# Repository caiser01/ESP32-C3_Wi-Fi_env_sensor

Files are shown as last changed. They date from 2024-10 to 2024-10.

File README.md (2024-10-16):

# ESP32-C3 Wi-Fi environment sensor node
<p>A Wi-Fi connected temperature, humidity, and pressure sensor node based around the Espressif ESP32-C3-MINI-1 and the Bosch BME280 Humidity/Pressure/Temperature sensor.</p>

<p align="center">
rev 1.0 PCB Revision 1.0 PCB
</p>

<p>The primary goal of this project is to provide a simple platform for monitoring the temperature and humidity of the spaces inside one's home. These wireless sensor nodes can be easily integrated with the free software packages such as Home Assistant (https://www.home-assistant.io) and ESPHome (https://esphome.io). Alternatively, the user can write their own fully custom firmware using ESP-IDF, Arduino, or MicroPython.</p>

<p>Through simple monitoring of the temperature and humidity in the different rooms of one's home it is possible to:
<br>
<ul>
  <li>Gain insight into the effectiveness of the home's heating and cooling (HVAC) system</li>
  <li>Determine if a space may need a humidifier/dehumidifier</li>
  <li>Identify spaces that may need additional insulation</li>
  <li>Find spaces with doors or windows that do not seal tightly</li>
</ul>
</p>
<p>Additionally, the barometric pressure sensing capability can provide realtime insight into changing local weather conditions.</p>

## Design
<p>This device was designed for measuring the basic ambient environmental conditions of an indoor space so that they may be remotely displayed instantly and/or logged for long-term monitoring. The ESP32-C3-MINI-1 was chosen for its small footprint and the numerous available coding frameworks including ESP-IDF, Arduino, MicroPython, and ESPHome. The device includes a built in charger for a lithium battery. The user has the option to power the sensor node from a USB-C cable or from a rechargeable lithium battery. Firmware flashing is also performed through the USB-C connector via the ESP32-C3's built in USB interface. Depending on the software and framework used, over-the-air (OTA) firmware flashing is also possible via Wi-Fi.</p>

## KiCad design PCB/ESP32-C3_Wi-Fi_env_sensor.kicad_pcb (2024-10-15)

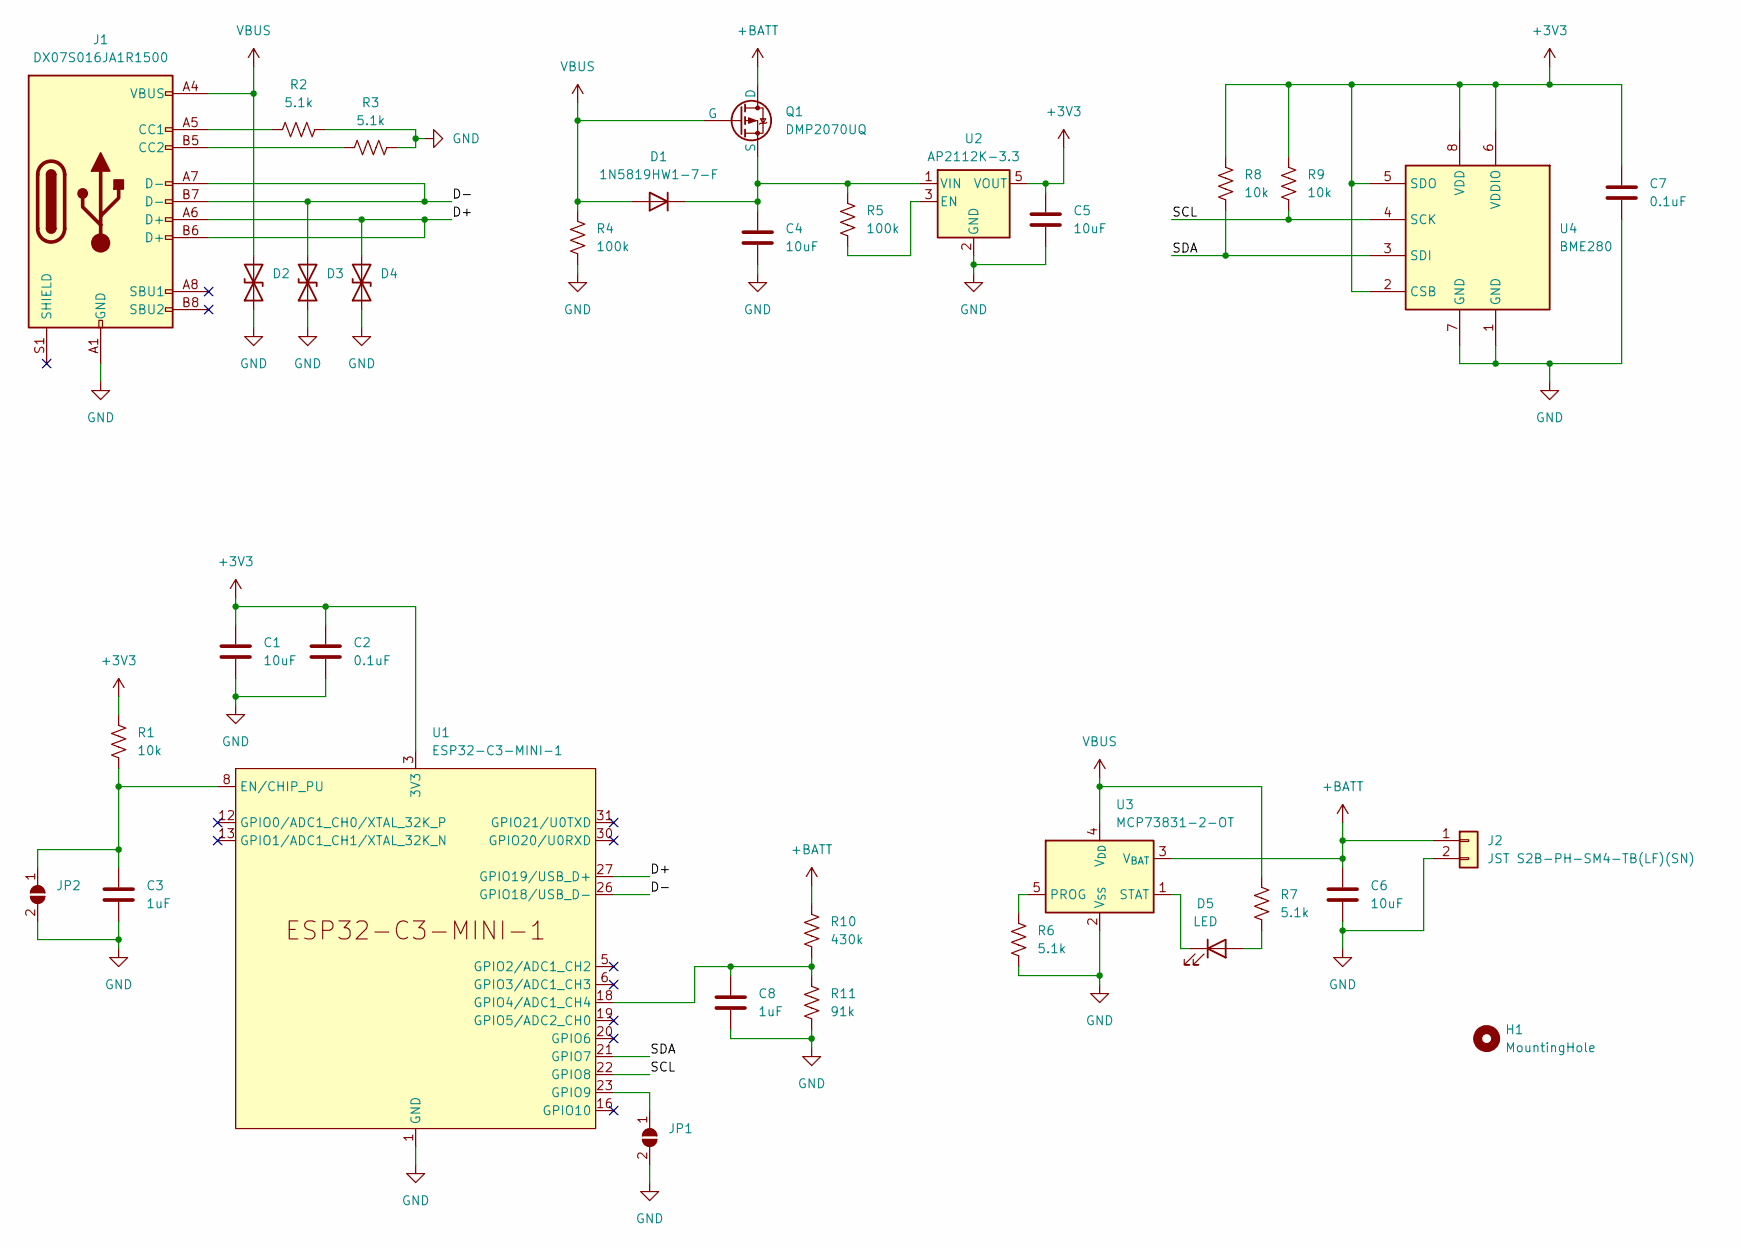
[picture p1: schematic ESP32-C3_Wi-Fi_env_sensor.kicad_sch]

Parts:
C1, C4, C5, C6: 10uF; C_0603_1608Metric_Pad1.08x0.95mm_HandSolder
C2, C7: 0.1uF; C_0603_1608Metric_Pad1.08x0.95mm_HandSolder
C3, C8: 1uF; C_0603_1608Metric_Pad1.08x0.95mm_HandSolder
D1: 1N5819HW1-7-F; D_SOD-123F
D2, D3, D4: LESD5D5.0CT1G; D_SOD-523
D5: LED; LED_0603_1608Metric_Pad1.05x0.95mm_HandSolder
H1: MountingHole; MountingHole_2.7mm_M2.5
J1: DX07S016JA1R1500; USB_C_Receptacle_JAE_DX07S016JA1R1500
J2: JST S2B-PH-SM4-TB(LF)(SN); JST_PH_S2B-PH-SM4-TB_1x02-1MP_P2.00mm_Horizontal
JP1, JP2: SolderJumper_2_Open; SolderJumper-2_P1.3mm_Open_Pad1.0x1.5mm
Q1: DMP2070UQ; SOT-23
R1, R8, R9: 10k; R_0402_1005Metric_Pad0.72x0.64mm_HandSolder
R2, R3, R6, R7: 5.1k; R_0603_1608Metric_Pad0.98x0.95mm_HandSolder
R4, R5: 100k; R_0603_1608Metric_Pad0.98x0.95mm_HandSolder
R10: 430k; R_0603_1608Metric_Pad0.98x0.95mm_HandSolder
R11: 91k; R_0603_1608Metric_Pad0.98x0.95mm_HandSolder
U1: ESP32-C3-MINI-1
U2: AP2112K-3.3; SOT-23-5
U3: MCP73831-2-OT; SOT-23-5
U4: BME280; Bosch_LGA-8_2.5x2.5mm_P0.65mm_ClockwisePinNumbering

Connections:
+3V3: C1.1, C2.1, C5.1, C7.1, R1.1, R8.1, R9.1, U1.3 (3V3), U2.5 (VOUT), U4.2 (CSB), U4.5 (SDO), U4.6 (VDDIO), U4.8 (VDD)
+BATT: C6.1, J2.1, Q1.3 (D), R10.1, U3.3 (V_{BAT})
/D+: D4.2 (A2), J1.A6 (D+), J1.B6 (D+), U1.27 (GPIO19/USB_D+)
/D-: D3.2 (A2), J1.A7 (D-), J1.B7 (D-), U1.26 (GPIO18/USB_D-)
/SCL: R9.2, U1.22 (GPIO8), U4.4 (SCK)
/SDA: R8.2, U1.21 (GPIO7), U4.3 (SDI)
GND: C1.2, C2.2, C3.2, C4.2, C5.2, C6.2, C7.2, C8.2, D2.1 (A1), D3.1 (A1), D4.1 (A1), J1.A1 (GND), J1.A12 (GND), J1.B1 (GND), J1.B12 (GND), J2.2, JP1.2 (B), JP2.2 (B), R2.2, R3.2, R4.2, R6.2, R11.2, U1.1 (GND), U1.2 (GND), U1.11 (GND), U1.14 (GND), U1.36 (GND), U1.37 (GND), U1.38 (GND), U1.39 (GND), U1.40 (GND), U1.41 (GND), U1.42 (GND), U1.43 (GND), U1.44 (GND), U1.45 (GND), U1.46 (GND), U1.47 (GND), U1.48 (GND), U1.49 (GND), U1.50 (GND), U1.51 (GND), U1.52 (GND), U1.53 (GND), U2.2 (GND), U3.2 (V_{SS}), U4.1 (GND), U4.7 (GND)
unnamed: C4.1, D1.1 (K), Q1.2 (S), R5.2, U2.1 (VIN)
unnamed: D5.2 (A), R7.2
unnamed: D5.1 (K), U3.1 (STAT)
unnamed: J1.A5 (CC1), R2.1
unnamed: J1.B5 (CC2), R3.1
unnamed: JP1.1 (A), U1.23 (GPIO9)
unnamed: C3.1, JP2.1 (A), R1.2, U1.8 (EN/CHIP_PU)
unnamed: C8.1, R10.2, R11.1, U1.18 (GPIO4/ADC1_CH4)
unnamed: R5.1, U2.3 (EN)
unnamed: R6.1, U3.5 (PROG)
VBUS: D1.2 (A), D2.2 (A2), J1.A4 (VBUS), J1.A9 (VBUS), J1.B4 (VBUS), J1.B9 (VBUS), Q1.1 (G), R4.1, R7.1, U3.4 (V_{DD})

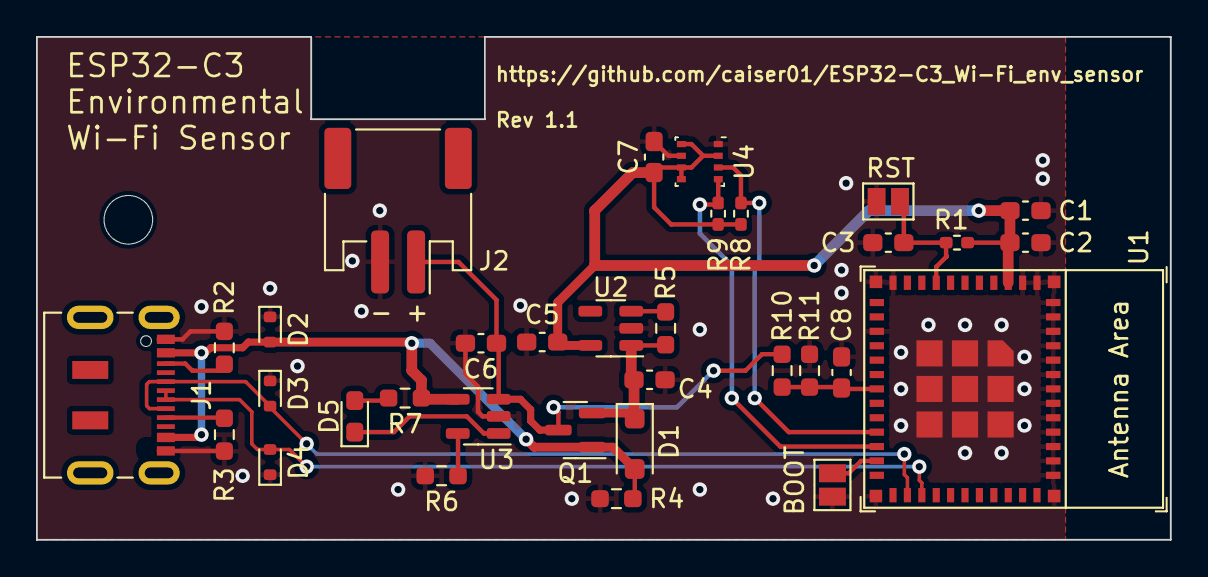
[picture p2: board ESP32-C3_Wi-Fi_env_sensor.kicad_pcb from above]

Board: 2 copper layers, 63.0 x 27.9 mm, 34 parts (0 on the bottom side), 18 nets.

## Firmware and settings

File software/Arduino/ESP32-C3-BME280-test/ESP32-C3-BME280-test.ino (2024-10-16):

/*
  Simple functional test for the ESP32-C3 Wi-Fi environment sensor node

  This program will interrogate the BME280 sensor and print out readings
  to the serial port to test basic functionality of the board

  ESP32 Arduino core must be installed
  (https://github.com/espressif/arduino-esp32)

  Set Arduino Tools menu options as follows:
  Board: ESP32C3 Dev Module
  USB CDC On Boot: Enabled
    
  Adapted from Example1_BasicReadings.ino by Nathan Seidle
  from SparkFun_BME280_Arduino_Library
  (https://github.com/sparkfun/SparkFun_BME280_Arduino_Library/)
*/

#include <Wire.h>

#include "SparkFunBME280.h"
BME280 mySensor;

void setup()
{
  Serial.begin(115200);
  Serial.println("Reading basic values from BME280");

  // board specific I2C pins SDA=GPIO7, SCL=GPIO8
  Wire.setPins(7, 8);
  
  Wire.begin();

  // SDO pin of BME280 is pulled high, address 0x77
  mySensor.setI2CAddress(0x77);
  if (mySensor.beginI2C() == false) //Begin communication over I2C
  {
    Serial.println("The sensor did not respond. Please check wiring.");
    while(1); //Freeze
  }
}

void loop()
{
  Serial.print("Humidity: ");
  Serial.print(mySensor.readFloatHumidity(), 0);

  Serial.print(" Pressure: ");
  Serial.print(mySensor.readFloatPressure(), 0);

  Serial.print(" Temp: ");
  //Serial.print(mySensor.readTempC(), 2);
  Serial.print(mySensor.readTempF(), 2);

  Serial.println();

  delay(50);
}

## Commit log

2024-09-19 Add KiCad PCB files
    [ESP32-C3_Wi-Fi_env_sensor.kicad_pcb, ESP32-C3_Wi-Fi_env_sensor.kicad_sch]
2024-09-19 Setup CAM output per PCBWay's instructions
    [ESP32-C3_Wi-Fi_env_sensor.kicad_pcb]
2024-10-15 Move U2, R5, C4 to make C4 more effective
    [ESP32-C3_Wi-Fi_env_sensor.kicad_pcb]
2024-10-16 Add revision 1.0 board photo
2024-10-16 Add photo of revision 1.0 PCB to README.md
2024-10-16 Add Arduino test program
2024-10-16 Change framework from esp-idf to arduino
